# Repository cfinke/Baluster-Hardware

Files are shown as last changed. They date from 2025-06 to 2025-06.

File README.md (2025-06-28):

3D-Printed Baluster Hardware
============================

These models are for assisting in the installation of new stairway balusters in an existing stairway.

My old balusters had 3/4" dowel tenons into the bottom stair treads and extended into 3/8" holes in the underside of the handrail.

My new balusters were 1/2" square on the bottom and 1/2" round on the top (transitioning into a 1/2" square). Specifically, they are a mix of these two balusters from Home Depot:

https://www.homedepot.com/p/EVERMARK-Stair-Parts-44-in-x-1-2-in-Matte-Black-Plain-Iron-Baluster-for-Stair-Remodel-I555B-044-HD00D/202088527

https://www.homedepot.com/p/EVERMARK-Stair-Parts-44-in-x-1-2-in-x-3-3-4-in-Matte-Black-Oval-Iron-Baluster-for-Stair-Remodel-I564B-044-HD00D/316139815

In order to fit the square pegs in the round holes, I modeled a socket for each end that would accept the end of the baluster and friction fit into the old hole.

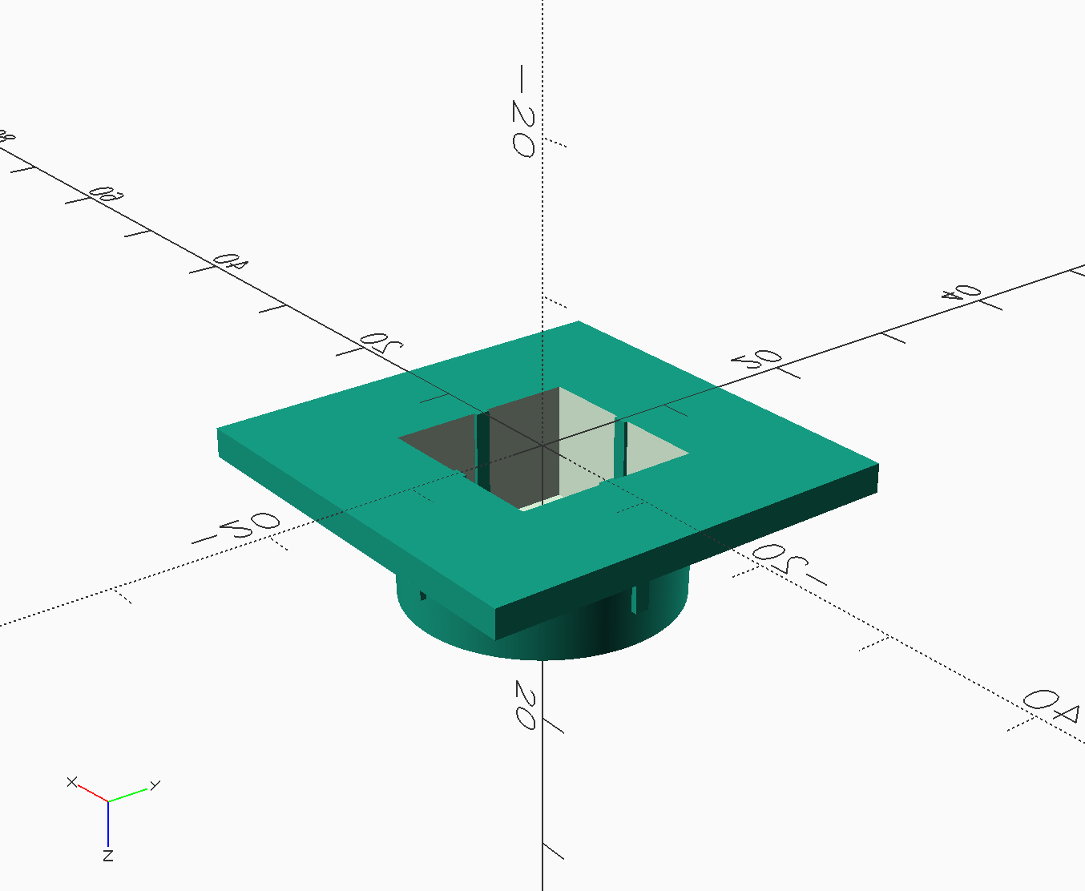
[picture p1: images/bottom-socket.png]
The bottom socket


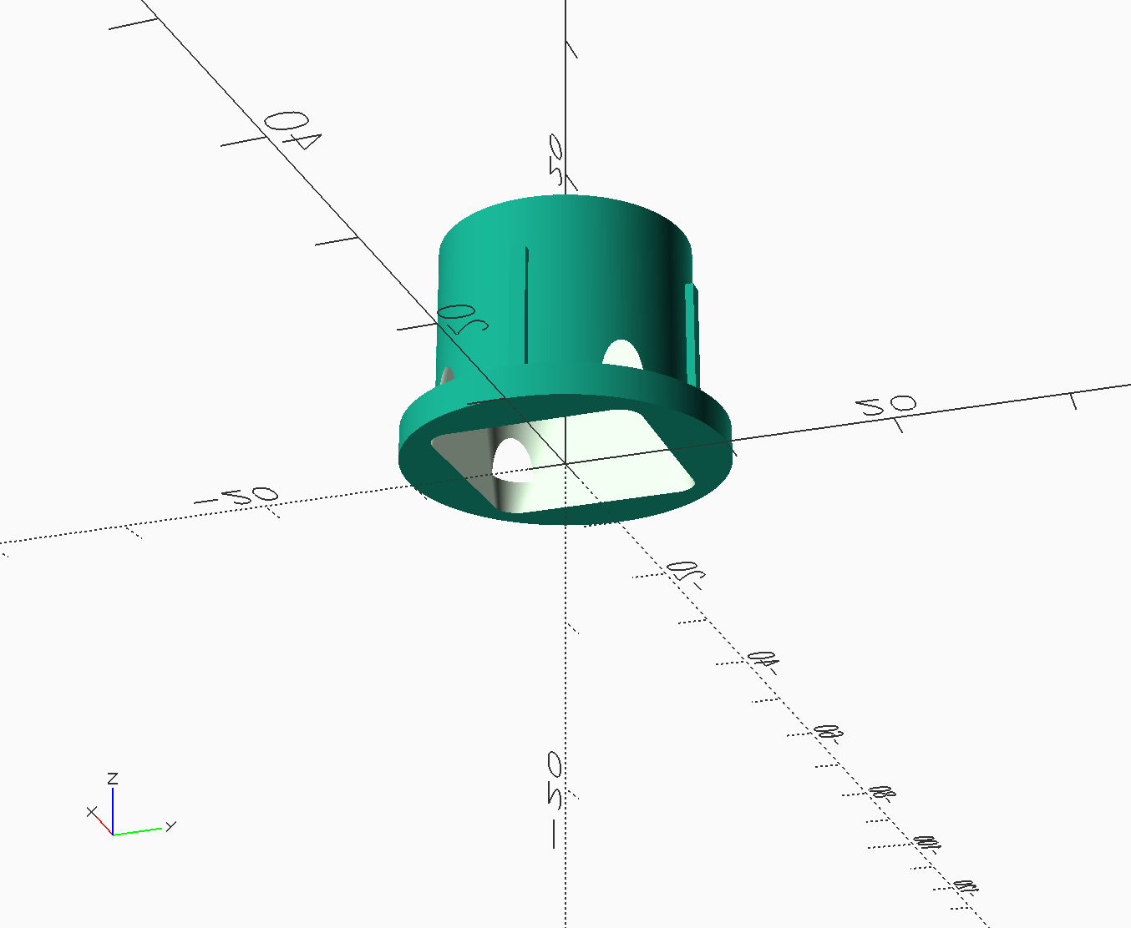
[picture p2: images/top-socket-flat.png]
The top socket


On the non-landing portion of the stairs, the top socket had an integrated angle:

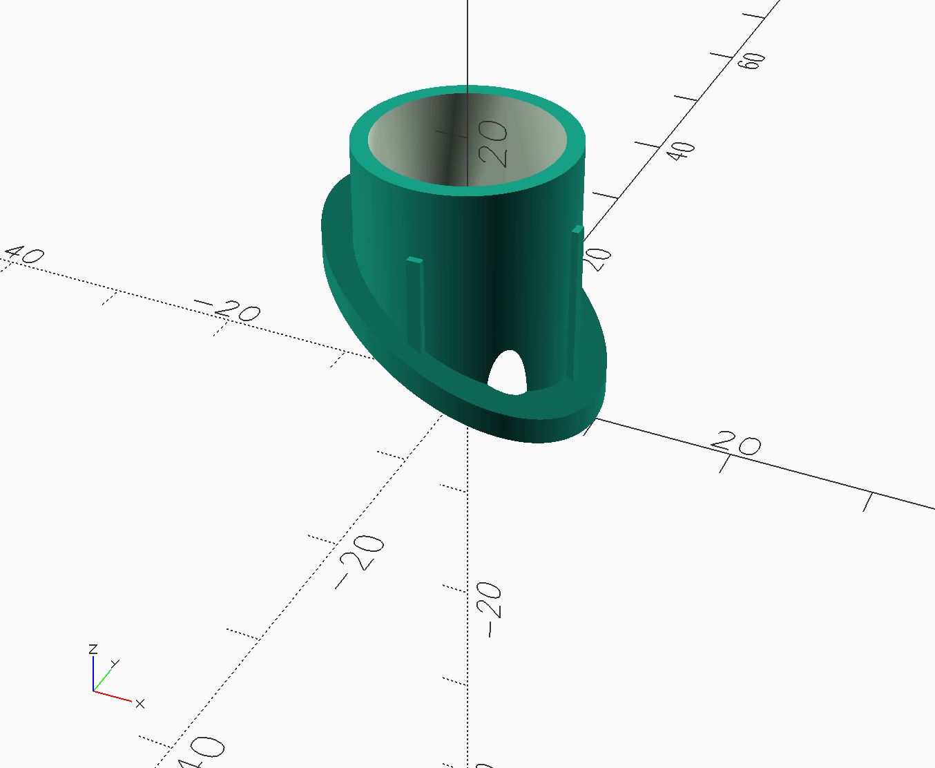
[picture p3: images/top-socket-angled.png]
The top socket for angled portions


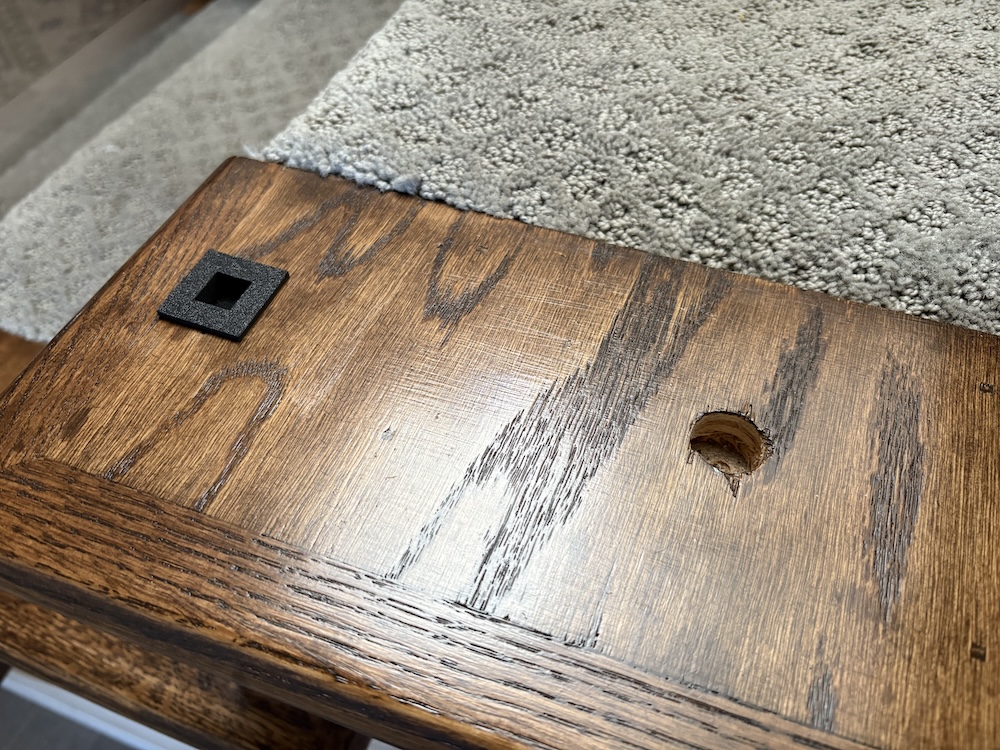
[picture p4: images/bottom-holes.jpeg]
An old baluster hole with and without an installed socket.


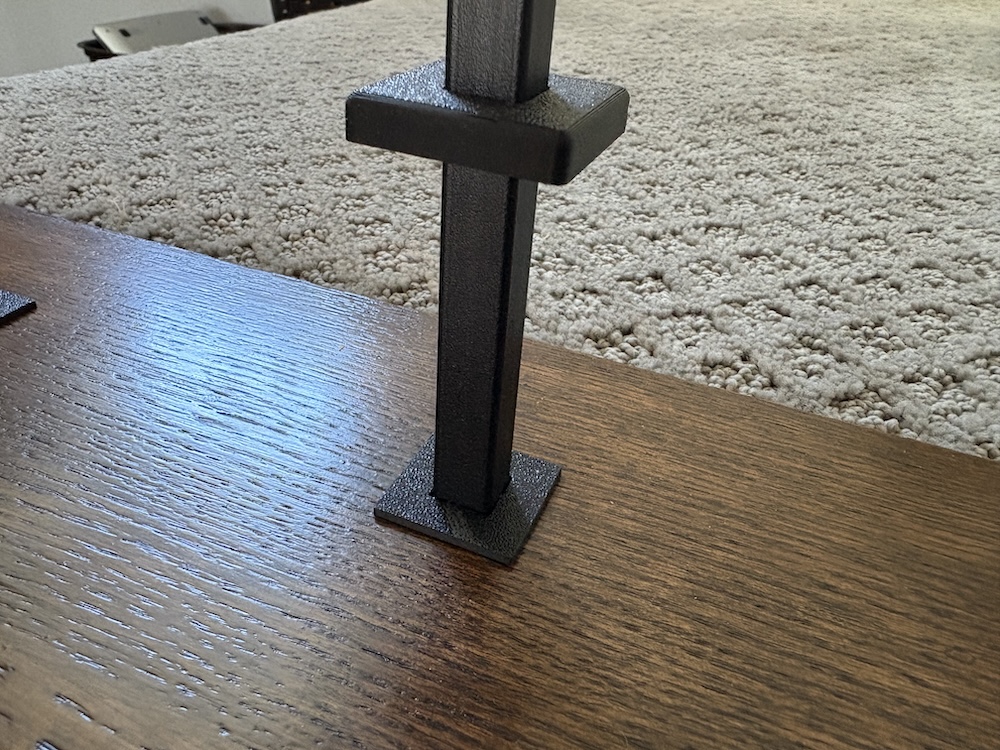
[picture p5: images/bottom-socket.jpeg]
The bottom of the baluster set inside the bottom socket.


I added friction ridges in each one to keep the balusters from rotating.

Finally, I modeled a shoe for the baluster to cover the bottom socket.

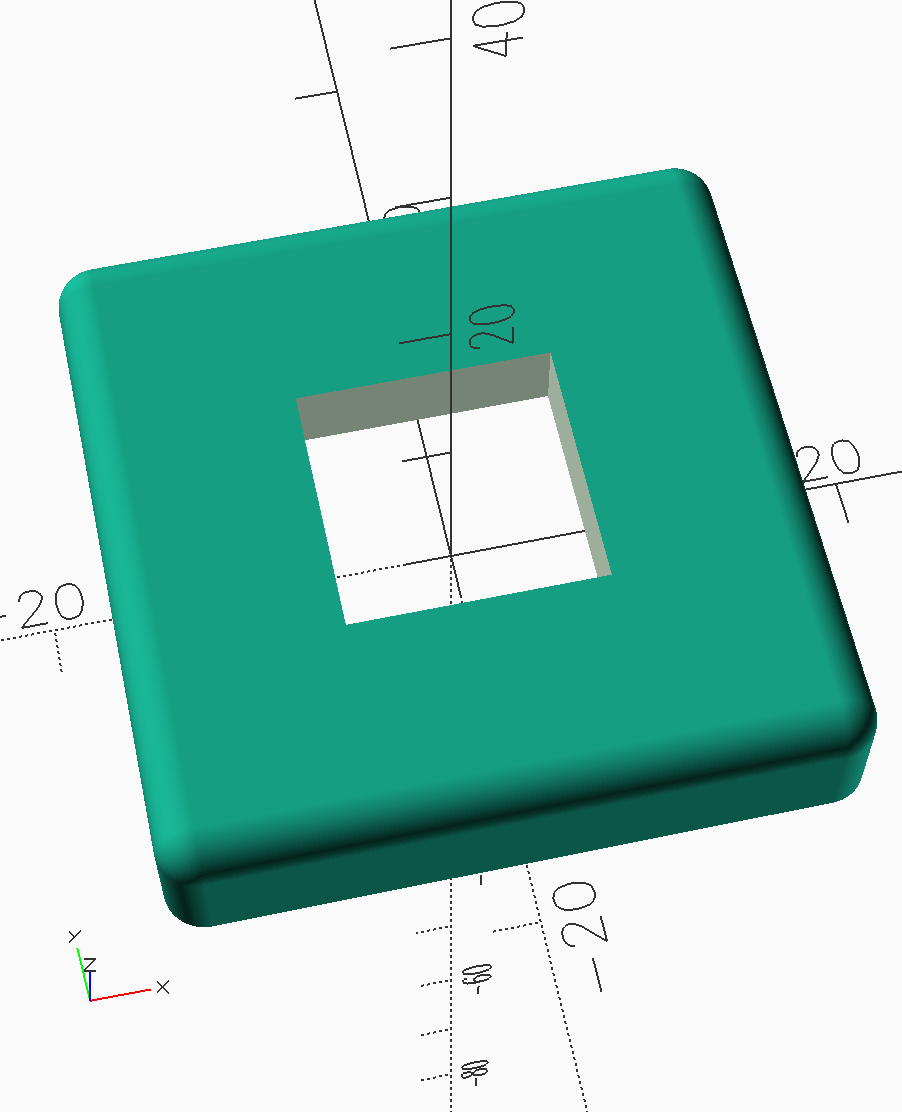
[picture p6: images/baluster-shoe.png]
The baluster shoe


(The top socket is unobtrusive and didn't need covering.) The shoe is modeled in the style of this commercially available shoe:

https://www.jmpwood.com/products/baluster-shoe-9054bs-square-1-2-square-base-shoe

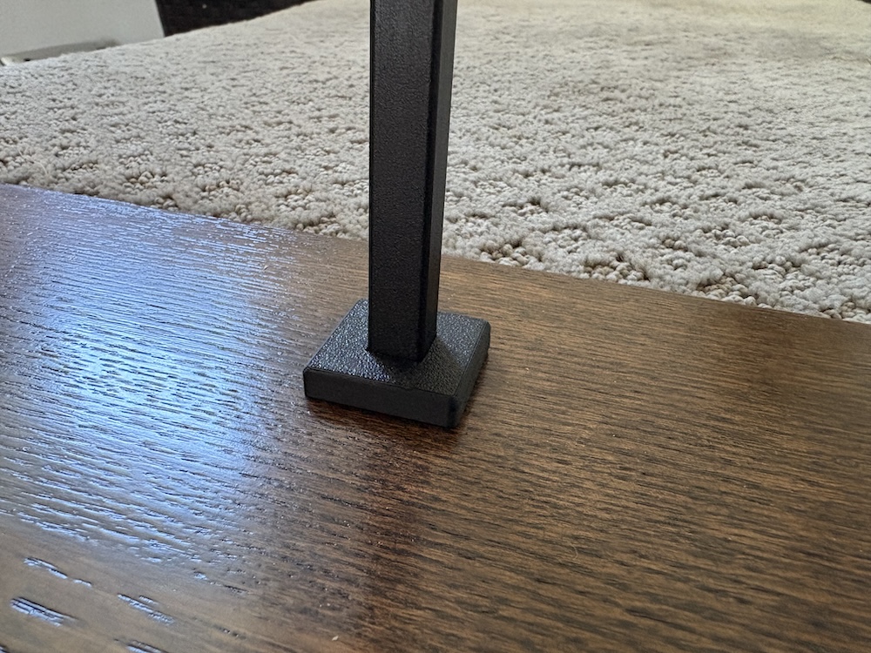
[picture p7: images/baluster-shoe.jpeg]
The installed baluster shoe.


To install the balusters, you fit the bottom socket into place, slide the shoe onto the bottom of the baluster, and place the top socket on top of the baluster. Angle the baluster, and insert the top into the underside of the railing. Continue pushing up while you position the bottom of the baluster over the bottom socket, and then push the bottom of the baluster down into the socket. Once it's seated, slide the top socket up into the hole, securing everything in place. For this to work, each baluster should be cut to 5/8" longer than the opening between the bottom stair tread and the underside of the railing. For balusters on the angled portion of the stairs, this should be 5/8" longer than the longest side of the baluster that will be exposed.

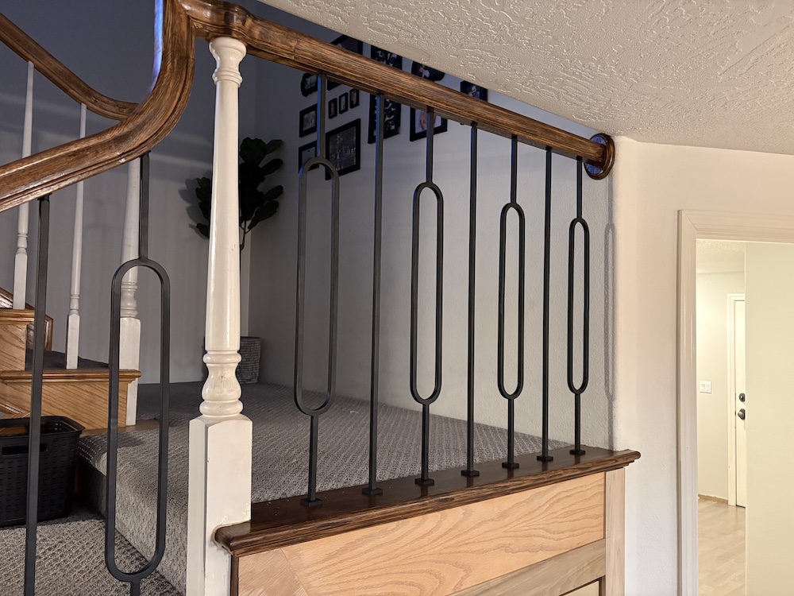
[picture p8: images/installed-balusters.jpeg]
The installed balusters


Now, the new balusters are completely installed without any modification to the stairway, and they're completely removable without any tools. The best of both worlds!

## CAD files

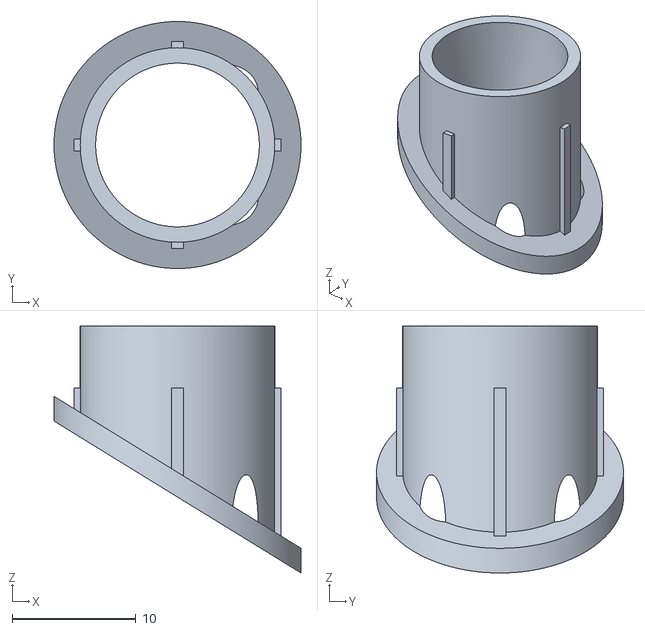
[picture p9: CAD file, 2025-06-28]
models/Baluster Top Socket (Angled).stl
20.0 x 20.0 x 20.0

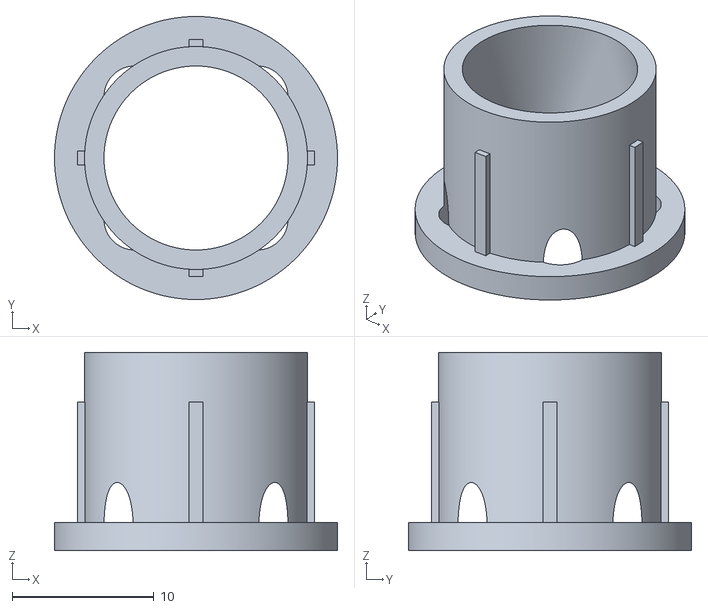
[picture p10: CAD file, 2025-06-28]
models/Baluster Top Socket (Flat).stl
20.0 x 20.0 x 14.0

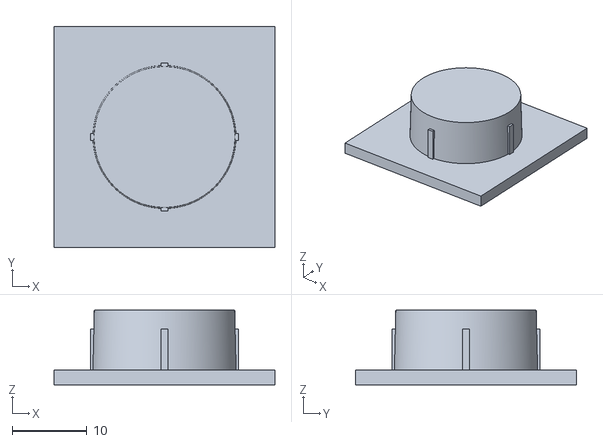
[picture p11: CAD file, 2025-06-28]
models/Baluster Bottom Socket.stl
29.5 x 29.5 x 10.0

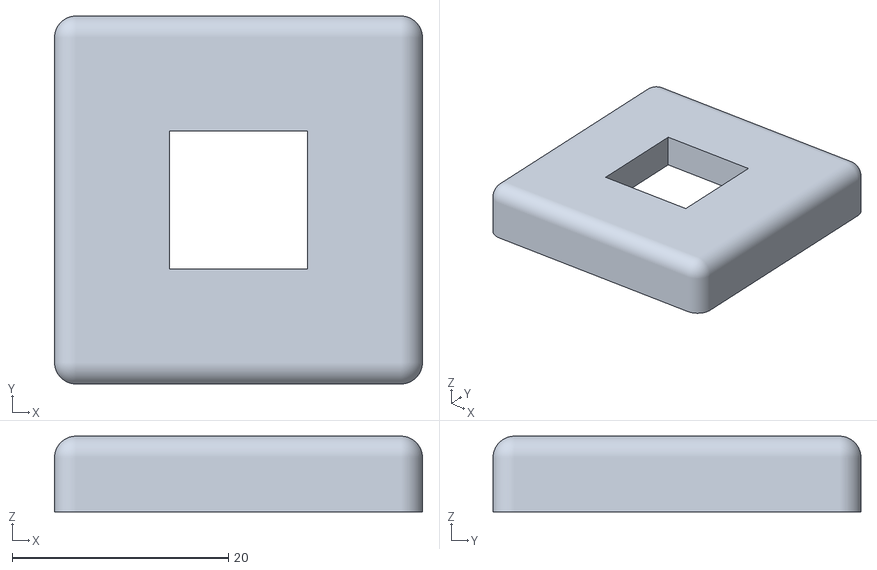
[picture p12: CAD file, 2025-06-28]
models/Baluster Shoe.stl
34.0 x 34.0 x 7.00

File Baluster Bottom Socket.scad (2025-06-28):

$fs = 0.1; $fa = 1;

/**
 * Originally designed to fit these two baluster models:
 *
 * Straight: https://www.homedepot.com/p/EVERMARK-Stair-Parts-44-in-x-1-2-in-Matte-Black-Plain-Iron-Baluster-for-Stair-Remodel-I555B-044-HD00D/202088527
 * Oval: https://www.homedepot.com/p/EVERMARK-Stair-Parts-44-in-x-1-2-in-x-3-3-4-in-Matte-Black-Oval-Iron-Baluster-for-Stair-Remodel-I564B-044-HD00D/316139815
 */
 
 /** Print with supports **/

hole_diameter = 19.25;
// hole_diameter = 19.75; // For holes that were more worn
hole_depth = 10;
insert_width = 13; // For straight
//insert_width = 12.75; // For oval
insert_floor_thickness = 2;
insert_depth = hole_depth - insert_floor_thickness;
screw_head_diameter = 9;
screw_thread_diameter = 4.5;

lip_width = 29.5;
lip_thickness = 2;

corner_radius = 1;

difference() {
	union() {
		cylinder( h = hole_depth, d2 = hole_diameter - .5, d1 = hole_diameter ); // Allow space for friction ridges
		
		linear_extrude( height = lip_thickness ) {
			square( size = [ lip_width, lip_width ], center = true );
		}
		
		// External friction ridges
		linear_extrude( height = hole_depth * 0.75 ) {
			square( size = [ hole_diameter + .5, 1 ], center = true ) ;
			rotate( [ 0, 0, 90 ] ) square( size = [ hole_diameter + .5, 1 ], center = true ) ;
		}

	}
	
	linear_extrude( insert_depth ) {
		square( size = [ insert_width, insert_width ], center = true  );
	}
}

// Internal friction ridges
linear_extrude( height = hole_depth * 0.75 ) {
	difference() {
		union() {
			square( size = [ hole_diameter, 1 ], center = true ) ;
			rotate( [ 0, 0, 90 ] ) square( size = [ hole_diameter, 1 ], center = true ) ;
		}
		
		square( size = [ insert_width - 0.5, insert_width - 0.5 ], center = true );
	}
}
	
	

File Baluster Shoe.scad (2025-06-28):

$fs = 0.1; $fa = 1;

/**
 * Originally designed to fit these two baluster models:
 *
 * Straight: https://www.homedepot.com/p/EVERMARK-Stair-Parts-44-in-x-1-2-in-Matte-Black-Plain-Iron-Baluster-for-Stair-Remodel-I555B-044-HD00D/202088527
 * Oval: https://www.homedepot.com/p/EVERMARK-Stair-Parts-44-in-x-1-2-in-x-3-3-4-in-Matte-Black-Oval-Iron-Baluster-for-Stair-Remodel-I564B-044-HD00D/316139815
 */
 
shoe_width = 34;
shoe_height = 7;
insert_width = 12.75; // For straight
// insert_width = 12.5; // For oval
shoe_wall_thickness = 4;
shoe_corner_radius = 2;

difference() {	
	// The rounded body of the shoe.
	minkowski() {
		difference() {
			linear_extrude( height = shoe_height - shoe_corner_radius ) {
				difference() {
					square( size = shoe_width - ( 2 * shoe_corner_radius ), center = true );
				}
			}
		}
		
		sphere( r = shoe_corner_radius );
	}
	
	// The negative space underneath
	linear_extrude( height = shoe_height - shoe_wall_thickness ) {
		square( size = shoe_width - shoe_wall_thickness, center = true );
	}
	
	// The hole for the baluster.
	linear_extrude( height = shoe_height ) {
		square( size = insert_width, center = true );
	}
	
	// Cut off the bottom where it was rounded underneath.
	translate( [ 0, 0, -shoe_corner_radius ] ) {
		linear_extrude( height = shoe_corner_radius ) {
			square( size = shoe_width, center = true );
		}
	}
}

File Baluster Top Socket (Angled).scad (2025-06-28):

$fs = 0.1; $fa = 1;

/**
 * Originally designed to fit these two baluster models:
 *
 * Straight: https://www.homedepot.com/p/EVERMARK-Stair-Parts-44-in-x-1-2-in-Matte-Black-Plain-Iron-Baluster-for-Stair-Remodel-I555B-044-HD00D/202088527
 * Oval: https://www.homedepot.com/p/EVERMARK-Stair-Parts-44-in-x-1-2-in-x-3-3-4-in-Matte-Black-Oval-Iron-Baluster-for-Stair-Remodel-I564B-044-HD00D/316139815
 */

hole_diameter = 16.75;
insert_height = 20;
insert_diameter = 13.25; // For straight balusters
//insert_diameter = 12.25; // For oval balusters
lip_diameter = 20;
lip_thickness = 2;

corner_radius = 1;

transition_length = ( 3 / 16 ) * 25.4;
baluster_width = 13; // For straight balusters
//baluster_width = 14; // For oval balusters
angle = 31.6; // Angle of the handrail relative to the ground.

intersection() {
	difference() {
		union() {
			cylinder( h = insert_height, d = hole_diameter - 1  );
			
			translate( [lip_diameter / 2, 0, lip_thickness ] )  {
				rotate( [0, angle, 0 ] ) {
					translate( [ 0, 0, -100 ] ) {
						linear_extrude( height = 100 ) {
							square( size = [ 100, 100 ], center = true );
						}
					}
				}
			}

			linear_extrude( height = lip_thickness ) {
				circle( d = lip_diameter );
			}
			
					linear_extrude( height = insert_height * 0.75 ) {
			square( size = [ hole_diameter, 1 ], center = true ) ;
			rotate( [ 0, 0, 90 ] ) square( size = [ hole_diameter, 1 ], center = true ) ;
		}

		}
		
		hull() {
			linear_extrude( insert_height ) {
				circle( d = insert_diameter );
			}
		
			translate( [0, 0, -transition_length - 1 ] ) {
				linear_extrude( 1 ) {
					square( size = [ baluster_width, baluster_width ], center = true );
				}
			}
		}
		
		translate( [lip_diameter / 2, 0, 0 ] )  {
			rotate( [0, angle, 0 ] ) {
				translate( [ 0, 0, -100 ] ) {
					linear_extrude( height = 100 ) {
						square( size = [ 100, 100 ], center = true );
					}
				}
			}
		}
		

	}
	
	cylinder( h = insert_height, d = lip_diameter );
}

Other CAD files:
Baluster Top Socket (Flat).scad
